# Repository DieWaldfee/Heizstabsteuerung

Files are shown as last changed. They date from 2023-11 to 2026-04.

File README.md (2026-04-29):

# Heizstabsteuerung

Heizstabsteuerung (Platine und Software) zur Ansteuerung eines Heizstabs in einem Pufferspeicher (Heizung)

**zugehörige Repositories**<br>

- PowerGuard (Steuerungsplatine <a href="https://github.com/DieWaldfee/PowerGuard"> Link </a>)
- Heizstabsteuerung (dieses Repository)
- Heizstab_ioBroker (Ansteuerungs-Blockly - ein MQTT-Broker wird benötigt - Link)

**Funktion:** <br>
Der ESP32 steuert 3 Temperatursensoren (DS18B20) an und liest diese aus. Zwei der Sensoren sollen am Referenzpunkt der Heizungsanlage (an Pufferspeichers der Heizung) angebracht werden, in dem auch der elektrische Heizstab eingeschraubt ist.
Die beiden Werte werden einerseits verglichen und andererseits benutzt, um die Pufferspeichertemperatur zu überwachen. Liegt die Temperatur zu hoch, dann ist zu viel Energie im Pufferspeicher und vermutlich ist der Heizstab dafür ursächlich -> der Heizstabsteuerung abgeschaltet (L1, L2, L3)und damit in den sicheren Zustand überführt.<p>
Liegt die Temperatur der beiden Sensoren über der eingestellten, kritischen Temperatur, so schaltet sich der ESP32 ganz ab und meldet dies optisch über die rote LED. Die Standardschaltung erfolgt über die beiden Sensoren. Eine Fehlerabschaltung erfolgt auch, wenn die Werte der Sensoren zu stark differieren (float deltaT = 2.0;).
Der dritte Sensor wird am höchsten Punkt des Pufferspeichers angebracht und dient der Überwachung der maximal zulässigen Puffertemperatur. Der Sensorwert wird zur Notabschaltung des ESP verwendet, sollte der Puffer signifikat zu heiß werden.
Die Kommunikation mit dem ESP32 wird über WiFi abgewickelt und über das Protokoll MQTT umgesetzt. Es stehen mehrere Befehle zur Verfügung, die ebenfalls via MQTT an den ESP gesendet werden kann. Neben "restart" (führt zu einem Neutstart des ESP32) kann die ganze Konfiguration un der debug-Level angepasst werden. Alle Anpassungen sind nach einem Neustart verlohren, da diese nicht permanet gespeichter werden (aber neue Parameter flashen geht ja fix). Befehle werden unter der MQTT-Hierarchie in folgendem Ort empfangen: "SmartHome/Keller/Heizung/ESP32_Heizstabsteuerung/command" (MQTT_SERIAL_RECEIVER_COMMAND)

**Hardwarevarianten:** <br>
Das Programm unterstützt zwei Hardwarevarianten in einem gemeinsamen Code. Die Auswahl erfolgt über den Parameter `HARDWARE_VERSION` in `src/secrets.h`:

- `HARDWARE_VERSION 1` → V1.0 Lochrasterplatine (OK-LED + ERROR-LED)
- `HARDWARE_VERSION 2` → V2.0 Platinenversion/PCB (OK-LED + MSG-LED + ERROR-LED)

**Entwicklungsumgebungen:** <br>
Die Software für den ESP32 wird mit **PlatformIO** (VSCode-Extension) entwickelt. Compile und Flash sind per Knopfdruck oder über `pio run --target upload` möglich. Die Installation ist sehr einfach und im Netz gut dokumentiert.<br>
Die Platine (PCB) habe ich in Eagle von AutoCAD modelliert. Für Maker gibt es eine kostenfreie Version. Die CAM-Daten (PCB-Produktionsdaten), sowie die BOM (Stückliste) sind ebenfalls aus Eagle ausgegeben.
Eine Übersichtsversion der Platine ist mit Fritzing umgesetzt und enthält auch einige Notizen zur Pinbelegung.<br>

**benötigte Umgebung:** <br>

- ioBroker zur Ansteuerung (geht natürlich auch mit anderen SmartHome-Systemen, solange diese MQTT sprechen können)
- ioBroker MGTT-Adapter
- MQTT-Broker: z.B. mosquitto unter Linux/Debian/Raspian...
- 230V Stromversorgung oder alternativ eine 5V Versorgung über z.B. ein USB-Ladegerät (muss 2 ESP32 sicher versorgen können -> 2A reicht völlig aus) oder über die Schraubklemmen anderweitig versorgt.

### Abhängigkeiten (PlatformIO – platformio.ini):

| Header | Bibliothek |
| --- | --- |
| `OneWire.h` | OneWire git-master (v2.3.7 inkompatibel mit ESP-IDF 5.x; v2.3.8 hat einen Bug – git-master enthält den Fix) |
| `DallasTemperature.h` | DallasTemperature by Miles Burton v4.0.4 |
| `WiFi.h` | Arduino / ESP32-Framework |
| `WiFiClient.h` | Arduino / ESP32-Framework |
| `PubSubClient.h` | PubSubClient by Nick O'Leary v2.8 |
| `Wire.h` | Arduino / ESP32-Framework |
| `LiquidCrystal_I2C.h` | LiquidCrystal_I2C by Frank de Brabander ^1.1.0 |
| `EmonLib.h` | EmonLib-esp32 – ESP32-optimierter Fork |
| `esp_task_wdt.h` | Espressif Framework |

### Board ESP32

Platform: `https://github.com/pioarduino/platform-espressif32` (Release 55.03.38-1)<br>
Board: `esp32dev`, Framework: `arduino`<br>

**aktuelle Versionen:** <br>

- ESP-Software V2.0.2
- PCB (Eagle) V2.0.1
- CAM V1.0
- BOM V2.0
- Fritzing V2.0

Die PCB V2.x ist für einen Platinenhersteller konstruiert => CAM-files können einfach der Bestellung beigefügt werden (z.B. bei https://jlcpcb.com für 2$ 5St Stand 11.11.2023) und ein paar Tage später ist die Platine fertig..
In der BOM findet sich die Stückliste für die Bestückung wieder.



Zugehöriges Projekt: https://github.com/users/DieWaldfee/projects/1

**Installation:**

- `src/secrets.h.example` nach `src/secrets.h` kopieren und eigene Zugangsdaten eintragen:<br>
  &nbsp;&nbsp;&nbsp;– WLAN-SSID, WLAN-Passwort, Hostname<br>
  &nbsp;&nbsp;&nbsp;– MQTT-Broker (IP, Port, User, Passwort)<br>
  &nbsp;&nbsp;&nbsp;– Hardwarevariante: `HARDWARE_VERSION 1` (Lochraster) oder `HARDWARE_VERSION 2` (Platine)<br>
  &nbsp;&nbsp;&nbsp;
- MQTT-Pfade sind in `src/Heizstabsteuerung.cpp` als `#define` hinterlegt und müssen in der Regel nicht geändert werden. <br>
  &nbsp;&nbsp;&nbsp;
- Adressen der DS18B20-Sensoren ermitteln und in `src/Heizstabsteuerung.cpp` eintragen. Hierzu muss der Debuglevel auf 1 gestellt werden (MQTT-Befehl `debug=1`) und die Ausgabe im Serial Monitor beobachtet werden. OnStart gibt der ESP32 die Sensoradressen aus.<br>
  &nbsp;&nbsp;&nbsp;
- Kalibrierung der Stromsensoren: Hierzu das separate Projekt **STC013_cal** (Sternverschaltung) bzw. **STC013_Dreieck_cal** (Dreiecksverschaltung) verwenden (siehe Abschnitt _Nachträgliche Kalibrierung_). <br>
  &nbsp;&nbsp;&nbsp;
- Bei Fehlern kann per MQTT-Befehl `debug=<0-3>` der Debug-Level für die Ausgaben auf den Serial Monitor eingestellt werden: 0 = BootUp only; 1 = Basic; 2 = Advanced; 3 = Absolut
- ESP-Software wird über PlatformIO auf das "ESP32 Dev Kit" compiliert und übertragen.
- Platine entweder via Eagle an PCB-Hersteller übermitteln oder mit einer Lochrasterplatine per Hand aufbauen.
- Platine bestücken + ESP und Level-Shifter (3.3V <-> 5V) aufsetzen.
- Relais anschließen.
- 12V Versorgung der Heizstabsteuerung wird über LED-Treiber realisiert.

**Displayinhalte:**

- Zeile 1;
  - L1 => Leiter 1 / Phase 1
  - L2 => Leiter 2 / Phase 2
  - L3 => Leiter 3 / Phase 3
  - hinter Lx: "-" => nicht geschaltet; "\*" => geschaltet
  - hinter Schaltzustand: "-" => ungeprüft; "x" => Fehler zwischen Strommessung und Soll-Schaltzustand; ":heavy_check_mark:" => Strommessung korrekt vs. Sollschaltzustand geprüft
  - hinter dem Block L3 folgt das Symbol für den Lüfterzustand: " " => Lüfter nicht geschaltet; ">>Lüftersymbol<<" => Lüfter geschaltet
  - hinter dem Lüftersymbol folgt MQTT-Symbol: " " => kein MQTT-Verbindung gegeben; "<<Wifi-Symbol>>" => MQTT-Verbingung aktiv
    Zeile 2:
  - T_Top: Temperatursensor am obersten Messpunkt - dient der Safety, um nicht zu überhitzen [°C]
  - T_Messpunkt_1: erste Messung auf der Entschiedungsebene (in der Regel parallel zum Sensor der Heizung) [°C]
  - T_Messpunkt_2: zweite Messung auf der Entschiedungsebene [°C]

**Steuerung:**

- Befehle werden über MQTT auf `/command` gesendet (Topic: `SmartHome/Keller/Heizung/ESP32_Heizstabsteuerung/command`).
- Befehlsliste (alle Befehle liegen in der MQTT-Callback-Funktion `void mqttCallback(...)`):
  - "L1 ein": schaltet L1 ein
  - "L1 aus": schaltet L1 aus
  - "L2 ein": schaltet L2 ein
  - "L2 aus": schaltet L2 aus
  - "L3 ein": schaltet L3 ein
  - "L3 aus": schaltet L3 aus
  - "L12 ein": schaltet L1 und L2 ein
  - "L12 aus": schaltet L1 und L2 aus
  - "L13 ein": schaltet L1 und L3 ein
  - "L13 aus": schaltet L1 und L3 aus
  - "L23 ein": schaltet L2 und L3 ein
  - "L23 aus": schaltet L2 und L3 aus
  - "L123 ein": schaltet L1, L2 und L3 ein
  - "L123 aus": schaltet L1, L2 und L3 aus
  - "Fan ein" / "Fan aus": schaltet den Lüfter ein/aus
  - "IrmsOn": startet die Stromsensor-Auswertung (befüllt Irms11/21/31 – Phase ein)
  - "IrmsOff": startet die Stromsensor-Auswertung (befüllt Irms10/20/30 – Phase aus)
  - "debug=\<0-3\>": setzt den Debug-Level (0=BootUp only; 1=Basic; 2=Advanced; 3=Absolut)
  - "panicMode=0": setzt den panicMode zurück
  - "thermalError=0" / "thermalError=1": setzt thermalError
  - "thermalLimit=0" / "thermalLimit=1": setzt thermalLimit
  - "checkError=0" / "checkError=1": setzt checkError
  - "ErrorLED aus": quittiert die Fehler-LED
  - "restart" / "reboot": führt zu einem Neustart des ESP32

**Nachträgliche Kalibrierung der Strommessung:**

Die SCT-013-Stromsensoren müssen für eine genaue Leistungsmessung individuell kalibriert werden, da ADC-Eingangswiderstände und Sensorexemplare streuen. Für die Kalibrierung stehen zwei separate PlatformIO-Projekte bereit — je nach Verschaltung des Heizstabs.

**Voraussetzungen:**

- Zangenampermeter zur Referenzmessung an allen drei Phasen
- Serieller Monitor (115200 Baud)
- Der Heizstab muss während der Lastmessung vollständig betriebsbereit angeschlossen sein

---

**Sternverschaltung — `STC013_cal` / `STC013_cal.cpp`**

Bei einem sternverschalteten Heizstab trägt jede Phase eine unabhängige Wicklung. Die Phasen werden nacheinander einzeln zugeschaltet.

Ablauf:

1. Referenzwerte mit dem Zangenampermeter unter Last an L1, L2 und L3 messen.
2. Die gemessenen Ströme in den Variablen `Irms_L1_xA`, `Irms_L2_xA`, `Irms_L3_xA` eintragen.
3. Sketch flashen und seriellen Monitor öffnen.

Der Sketch führt für jede Phase automatisch zwei Messreihen durch:

- **Nullmessung** (Last aus): 10 Messungen ohne Strom; die ersten 3 werden verworfen. Der Mittelwert der verbleibenden 7 Messungen ergibt den empfohlenen neuen Wert für `ADC_LX_zeroCorr`. Dieser Offset korrigiert den Leckstrom des Sensors im stromlosen Zustand.
- **Lastmessung** (Last ein): Das zugehörige SSR wird zugeschaltet. Aus dem Mittelwert der 7 gültigen Messungen und dem Referenzwert vom Zangenampermeter berechnet der Sketch den neuen `ADC_LX_corr`-Faktor nach der Formel:

```
ADC_LX_corr_neu = (Irms_Referenz / Irms_gemessen) * ADC_LX_corr_alt
```

4\. Die ausgegebenen Korrekturwerte für `ADC_LX_corr` und `ADC_LX_zeroCorr` in `src/Heizstabsteuerung.cpp` übernehmen und neu flashen.

Der `loop()` wiederholt die gesamte Messreihe automatisch, sodass mehrere Durchläufe für eine stabile Mittelung genutzt werden können.

---

**Dreiecksverschaltung — `STC013_Dreieck_cal` / `STC013_Dreieck_cal.cpp`**

Bei einem dreiecksverschalteten Heizstab fließen die Strangströme durch die Wicklungen zwischen den Phasen. Die Kalibrierung erfolgt stufenweise, weil sich der Laststrom in L3 erst bei Stufe 2 (alle drei Phasen aktiv) vollständig ausbildet.

Schaltstufen:

| Stufe | Aktive Phasen | Beschreibung |
| ----- | --- | --- |
| 1 | L1 + L2 | Eine Dreieckwicklung zwischen L1 und L2 |
| 2 | L1 + L2 + L3  | Alle drei Wicklungen aktiv |

Ablauf:

1. Referenzwerte mit dem Zangenampermeter messen:
   - L1 und L2 in **Stufe 1** (nur L1 + L2 eingeschaltet)
   - L3 in **Stufe 2** (alle drei Phasen eingeschaltet)
2. Werte eintragen: `Irms_L1_xA` und `Irms_L2_xA` für Stufe 1, `Irms_L3_xA` für Stufe 2.
3. Sketch flashen und seriellen Monitor öffnen.

Der Sketch führt zunächst Nullmessungen für alle drei Sensoren durch (alle Phasen aus), dann:

- **Stufe 1**: L1 und L2 werden zugeschaltet — Kalibrierung von `ADC_L1_corr` und `ADC_L2_corr`
- **Stufe 2**: L3 wird zusätzlich zugeschaltet — Kalibrierung von `ADC_L3_corr`

Auch hier werden je 10 Messungen durchgeführt, die ersten 3 verworfen und aus den verbleibenden 7 der Mittelwert gebildet. Die Korrekturformel ist identisch zur Sternverschaltung.

4\. Die ausgegebenen Korrekturwerte für `ADC_LX_corr` und `ADC_LX_zeroCorr` in `src/Heizstabsteuerung.cpp` übernehmen und neu flashen.

---

**Kalibrierparameter in `src/Heizstabsteuerung.cpp`:**

| Parameter | Bedeutung |
| --- | --- |
| `ADC_L1_corr` / `ADC_L2_corr` / `ADC_L3_corr` | Skalierungsfaktor für EmonLib (Rohwert → Ampere) |
| `ADC_L1_zeroCorr` / `ADC_L2_zeroCorr` / `ADC_L3_zeroCorr` | Offset-Korrektur für Leckstrom bei stromlosem Sensor |

---

Alternativ kann die manuelle Methode über MQTT verwendet werden:

- Phasenlimits temporär erhöhen: `phasen1Limit=100`
- Phasen ausschalten: `L123 aus`, dann `IrmsOff` → Irms10/20/30 werden befüllt
- Phasen einschalten: `L123 ein`, dann `IrmsOn` → Irms11/21/31 werden befüllt
- Tatsächlichen Strom parallel mit Zangenampermeter messen
- Korrekturwerte berechnen: ADC_L1_corr = Asoll/Aist × 15A
- Phasen ausschalten: `L123 aus`, dann `reboot`

**Bezugsquellen:**

- Platinennetzteil AC-05-3 <a href="https://www.azdelivery.de/products/copy-of-220v-zu-5v-mini-netzteil"> AZ-Delivery </a>
- Levelshifter (3.3V <-> 5V) <a href="https://www.amazon.de/RUNCCI-YUN-Pegelwandler-Converter-BiDirektional-Mikrocontroller/dp/B082F6BSB5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"> Amazon </a>
- Relais <a href="https://www.amazon.de/gp/product/B0B5816YJ7/ref=ppx_yo_dt_b_search_asin_image?ie=UTF8&th=1"> Amazon </a> oder <a href="https://www.az-delivery.de/products/relais-modul"> AZ Delivery </a>
- SSR-40DA, Eingang 4-32VDC <a href="https://www.amazon.de/gp/product/B071HP9NJD/ref=ppx_yo_dt_b_search_asin_title?ie=UTF8&psc=1"> Amazon </a>
- 12V LED-Treiber als Schaltspannung der SSR-Relais <a href="https://www.amazon.de/gp/product/B082NLNCSB/ref=ppx_yo_dt_b_search_asin_image?ie=UTF8&psc=1"> Amazon </a>
- JST-Buchse <a href="https://www.amazon.de/gp/product/B0B2R99X99/ref=ppx_yo_dt_b_search_asin_title?ie=UTF8&psc=1"> Amazon </a>
- Klemmbuchse <a href="https://www.amazon.de/gp/product/B087RN8FDZ/ref=ppx_yo_dt_b_search_asin_title?ie=UTF8&th=1"> Amazon </a>
- Widerstände 4,7kOhm, 220 Ohm, 330 Ohm, Led grün und rot Amazon / eBay / Conrad...
- Temperatursensoren DS18B20 <a href="https://www.az-delivery.de/products/2er-set-ds18b20-mit-3m-kabel"> AZ Delivery </a>
- Display 16x2 (I2C) <a href="https://www.az-delivery.de/products/bundlelcd-schnittstelle"> AZ Delivery </a>
- Sensor SCT013 (15A-Version) <a href="https://www.ebay.de/itm/401649505325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"> eBay </a>

**fertige Steuerung:**

(Displayanzeige mit Schaltzustand der Phasen L1-L3, Lüfter, MQTT-Connect in der ersten Zeile. DIe zweite Zeile zeigt die Temperaturen Max am höchsten Punkt und den Sensor 1 und 2 am Relegungspunkt)

(bestückte Heizstabsteuerung mit angeschlossenen Strom-Sensoren und Display - ohne Temperatursensoren)

(bestückte Heizstabsteuerung mit angeschlossenen Strom-Sensoren und Display - ohne Temperatursensoren)

(Gesamtschaltung am Pufferspeicher - links die Steuerung und rechts die SSR-Relais und deren Kühlkörper)

**Haftungsausschluss**<br>
Deutsch: Dieses Projekt arbeitet mit Netzspannung (220 V) und darf ausschließlich von qualifiziertem Fachpersonal aufgebaut, installiert und betrieben werden. Durch die anliegende Spannung besteht Lebensgefahr! Fehler in Schaltung oder Software können zu Sachschäden (z. B. an Gebäude oder Heizung) oder zu gefährlichen Situationen für Leib und Leben führen. Nutzung auf eigene Gefahr – jegliche Haftung wird ausgeschlossen.
<br>
English: This project operates with mains voltage (220 V) and must only be assembled, installed, and operated by qualified professionals. The present voltage poses a risk of fatal electric shock! Errors in circuitry or software may cause property damage (e.g., to buildings or heating systems) or create life-threatening situations. Use at your own risk – any liability is disclaimed.

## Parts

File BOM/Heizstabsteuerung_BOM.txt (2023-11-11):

Stückliste exportiert aus C:/ESP32_Projekte/Heizstabsteuerung/Eagle/Heizstabsteuerung_V2.02.sch am 11.11.2023 21:42

Part    Value              Device             Package            Description                                         AVAILABILITY CHECK_PRICES                                                                     DESCRIPTION                                                MF                                                                                         MP                MPN           OC_FARNELL OC_NEWARK PACKAGE POPULARITY PRICE PURCHASE-URL                                           SNAPEDA_LINK SPICEPREFIX                                                                      
C1      10µF               CPOL-EUE2.5-5      E2,5-5             POLARIZED CAPACITOR, European symbol                                                                                                                                                                                                                                                                                                                                 16                                                                                   C                                                                                
C2      10µF               CPOL-EUE2.5-5      E2,5-5             POLARIZED CAPACITOR, European symbol                                                                                                                                                                                                                                                                                                                                 16                                                                                   C                                                                                
C3      10µF               CPOL-EUE2.5-5      E2,5-5             POLARIZED CAPACITOR, European symbol                                                                                                                                                                                                                                                                                                                                 16                                                                                   C                                                                                
CON1                       WAGO-500-2         WAGO-500-2         WAGO SCREW CLAMP                                                                                                                                                                                                                                                                                                          237-102       unknown    70K9898           32                                                                                                                                                                    
CON2    JST-XH-03          JST-XH-03          JST-XH-03                                                                                                                                                                                                                                                                                                                                                                                                                                                                                                                                                     
CON3    JST-XH-03          JST-XH-03          JST-XH-03                                                                                                                                                                                                                                                                                                                                                                                                                                                                                                                                                     
CON4    JST-XH-03          JST-XH-03          JST-XH-03                                                                                                                                                                                                                                                                                                                                                                                                                                                                                                                                                     
JP1     Display 16x2       JP4E               JP4                JUMPER                                                                                                                                                                                                                                                                                                                                                               15                                                                                                                                                                    
JP3     L1                 JP1E               JP1                JUMPER                                                                                                                                                                                                                                                                                                                                                               61                                                                                                                                                                    
JP4     L2                 JP1E               JP1                JUMPER                                                                                                                                                                                                                                                                                                                                                               61                                                                                                                                                                    
JP5     L3                 JP1E               JP1                JUMPER                                                                                                                                                                                                                                                                                                                                                               61                                                                                                                                                                    
LED1    rot                LED3MM             LED3MM             LED                                                                                                                                                                                                                                                                                                                                                                  97                                                                                                                                                                    
LED2    grün               LED3MM             LED3MM             LED                                                                                                                                                                                                                                                                                                                                                                  97                                                                                                                                                                    
LED3    gelb               LED3MM             LED3MM             LED                                                                                                                                                                                                                                                                                                                                                                  97                                                                                                                                                                    
LS_SSR1 LEVELSHIFTER       LEVELSHIFTER       LEVELSHIFTER       Logic Level Converter - Bi-Direc Check availability In Stock                                                                                       BSS138 Logic-Level Translator Interface Evaluation Board  SparkFun                                                                                   BOB-12009                                            None               None  https://pricing.snapeda.com/search?q=BOB-12009&ref=eda                                                                                               
R1      220                R_10MM0207/10      0207/10            RESISTOR, European symbol                                                                                                                                                                                                                                                                                                                                            81                                                                                   R                                                                                
R2      330                R_10MM0207/10      0207/10            RESISTOR, European symbol                                                                                                                                                                                                                                                                                                                                            81                                                                                   R                                                                                
R3      10k                R_10MM0207/10      0207/10            RESISTOR, European symbol                                                                                                                                                                                                                                                                                                                                            81                                                                                   R                                                                                
R4      4.7 k              R_10MM0207/10      0207/10            RESISTOR, European symbol                                                                                                                                                                                                                                                                                                                                            81                                                                                   R                                                                                
R5      10k                R_10MM0207/10      0207/10            RESISTOR, European symbol                                                                                                                                                                                                                                                                                                                                            81                                                                                   R                                                                                
R6      10k                R_10MM0207/10      0207/10            RESISTOR, European symbol                                                                                                                                                                                                                                                                                                                                            81                                                                                   R                                                                                
R7      10k                R_10MM0207/10      0207/10            RESISTOR, European symbol                                                                                                                                                                                                                                                                                                                                            81                                                                                   R                                                                                
R8      10k                R_10MM0207/10      0207/10            RESISTOR, European symbol                                                                                                                                                                                                                                                                                                                                            81                                                                                   R                                                                                
R9      10k                R_10MM0207/10      0207/10            RESISTOR, European symbol                                                                                                                                                                                                                                                                                                                                            81                                                                                   R                                                                                
R10     220                R_10MM0207/10      0207/10            RESISTOR, European symbol                                                                                                                                                                                                                                                                                                                                            81                                                                                   R                                                                                
SV1                        FE06-1             FE06               FEMALE HEADER                                                                                                                                                                                                                                                                                                                           unknown    unknown           11                                                                                                                                                                    
SV2                        FE06-1             FE06               FEMALE HEADER                                                                                                                                                                                                                                                                                                                           unknown    unknown           11                                                                                                                                                                    
U$1     LOGO_RAUCHSCHWALBE LOGO_RAUCHSCHWALBE LOGO_RAUCHSCHWALBE                                                                                                                                                                                                                                                                                                                                                                                                                                                                                                                                            
U1      ESP32-DEV-KIT-V4   ESP32-DEV-KIT-V4   ESP32-DEV-KIT-V4   ESP32-DEVKITC Check availability                    In Stock     https://www.snapeda.com/parts/ESP32-DEVKITC/Espressif+Systems/view-part/?ref=eda  ESP32-WROOM-32UE series Transceiver                        802.11 b/g/n (Wi-Fi, WiFi, WLAN), Bluetooth ® Smart Ready 4.x Dual Mode Evaluation Board  Espressif Systems ESP32-DEVKITC                              None             None                                                                https://www.snapeda.com/parts/ESP32-DEVKITC/Espressif+Systems/view-part/?ref=snap

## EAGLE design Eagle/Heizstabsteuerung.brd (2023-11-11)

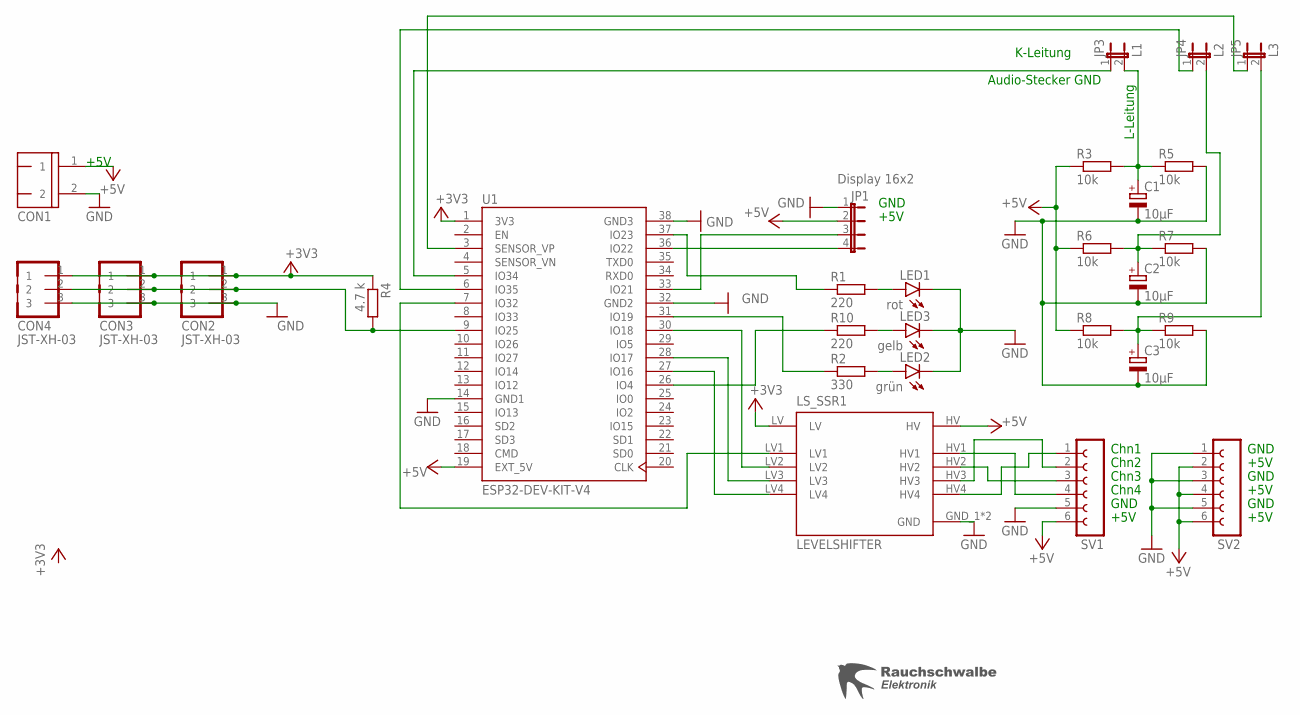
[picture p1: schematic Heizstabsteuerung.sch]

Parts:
C1, C2, C3: 10µF; E2,5-5
CON1: WAGO-500-2
CON2, CON3, CON4: JST-XH-03
JP1: Display 16x2; JP4
JP3: L1; JP1
JP4: L2; JP1
JP5: L3; JP1
LED1: rot; LED3MM
LED2: grün; LED3MM
LED3: gelb; LED3MM
LS_SSR1: LEVELSHIFTER
R1, R10: 220; 0207/10
R2: 330; 0207/10
R3, R5, R6, R7, R8, R9: 10k; 0207/10
R4: 4.7 k; 0207/10
SV1, SV2: FE06-1; FE06
U1: ESP32-DEV-KIT-V4
U$1: LOGO_RAUCHSCHWALBE

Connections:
+3V3: CON2.1, CON3.1, CON4.1, LS_SSR1.LV, R4.1, U1.1 (3V3)
+5V: CON1.1, JP1.2, LS_SSR1.HV, R3.1, R6.1, R8.1, SV1.6, SV2.2, SV2.4, SV2.6, U1.19 (EXT_5V)
GND: C1.-, C2.-, C3.-, CON1.2, CON2.3, CON3.3, CON4.3, JP1.1, LED1.K (C), LED2.K (C), LED3.K (C), LS_SSR1.GND_1 (GND), LS_SSR1.GND_2 (GND), R5.2, R7.2, R9.2, SV1.5, SV2.1, SV2.3, SV2.5, U1.14 (GND1), U1.32 (GND2), U1.38 (GND3)
unnamed: R1.1, U1.37 (IO23)
unnamed: C1.+, JP3.2, R3.2, R5.1
unnamed: LED3.A, R10.2
unnamed: JP1.3, U1.33 (IO21)
unnamed: JP1.4, U1.36 (IO22)
unnamed: R2.1, U1.31 (IO19)
unnamed: LED1.A, R1.2
unnamed: LED2.A, R2.2
unnamed: LS_SSR1.HV4, SV1.1
unnamed: LS_SSR1.LV1, U1.7 (IO32)
unnamed: CON2.2, CON3.2, CON4.2, R4.2, U1.9 (IO25)
unnamed: JP3.1, U1.5 (IO34)
unnamed: LS_SSR1.LV4, U1.27 (IO16)
unnamed: LS_SSR1.LV3, U1.28 (IO17)
unnamed: LS_SSR1.LV2, U1.30 (IO18)
unnamed: R10.1, U1.26 (IO4)
unnamed: LS_SSR1.HV1, SV1.4
unnamed: LS_SSR1.HV2, SV1.3
unnamed: LS_SSR1.HV3, SV1.2
unnamed: JP4.1, U1.6 (IO35)
unnamed: JP5.1, U1.3 (SENSOR_VP)
unnamed: C2.+, JP4.2, R6.2, R7.1
unnamed: C3.+, JP5.2, R8.2, R9.1

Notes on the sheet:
GND
+5V
Chn1
Chn2
Chn3
Chn4
K-Leitung
L-Leitung
Audio-Stecker GND

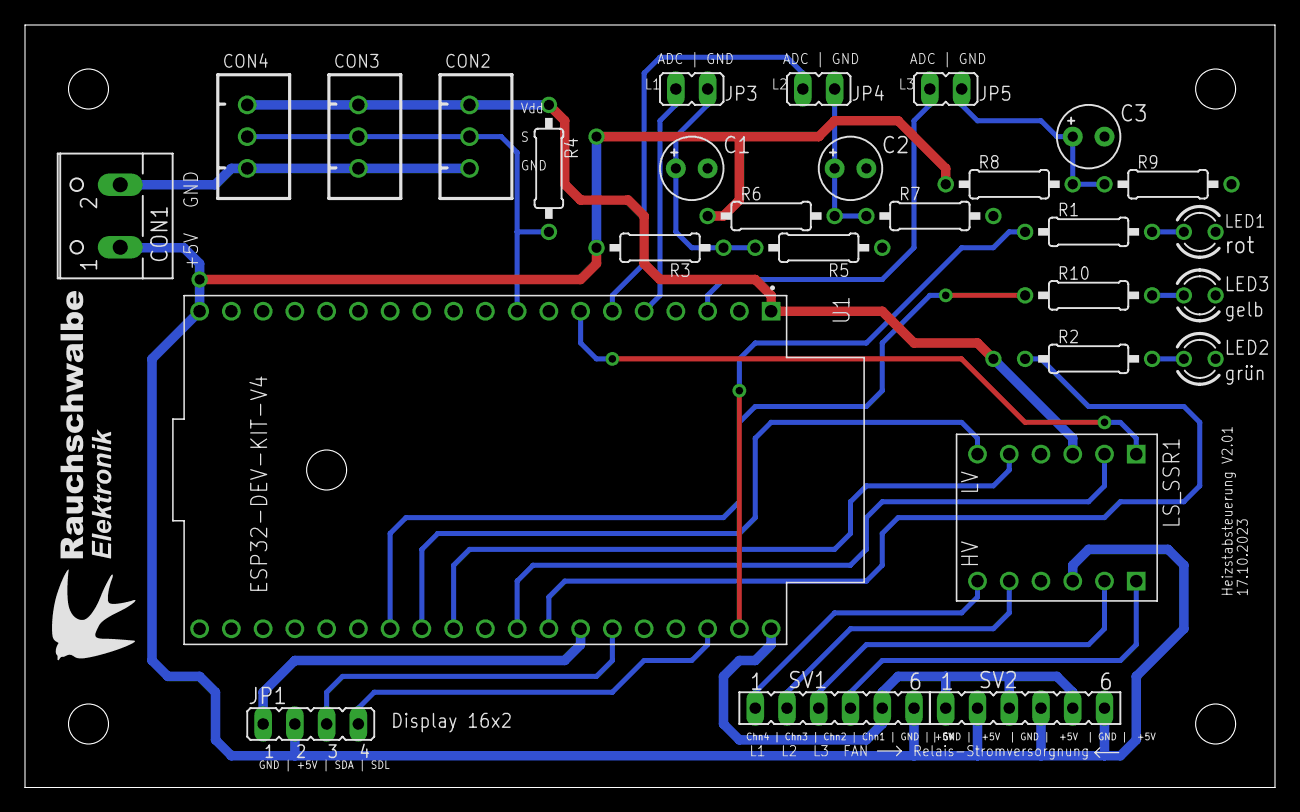
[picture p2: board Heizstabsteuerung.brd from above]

Board: 2 copper layers, 100.0 x 61.0 mm, 29 parts (0 on the bottom side), 26 nets.

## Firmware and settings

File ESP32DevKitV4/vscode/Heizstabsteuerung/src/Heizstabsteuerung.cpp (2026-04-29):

// https://beelogger.de/sensoren/temperatursensor-ds18b20/ für Pinning und
// Anregung
#include <DallasTemperature.h>
#include <EmonLib.h>  // Auswertung der SCT013-Sensoren
#include <LiquidCrystal_I2C.h>
#include <OneWire.h>
#include <PubSubClient.h>
#include <WiFi.h>
#include <WiFiClient.h>
#include <Wire.h>
#include <esp_task_wdt.h>

#include "hardware.h"
#include "secrets.h"

static byte debug = 0;
static String lastError = "";

// Sicherheitsfunktionen
int volatile thermalError = 0;        // Indikator für die thermische Zwangsabschaltung - die Obergrenze die
                                      // Max-Sensors ist überschritten -> PanicMode = 1
int volatile thermalLimit = 0;        // Indikator, das die maximale Temperatur am Top-Sensor überschritten
                                      // wurde. Phasen werden abgeschalten.
int volatile thermalMaxOverheat = 0;  // Indikator, das die maximale Temperatur am Max-Sensor überschritten
                                      // wurde. Phasen werden abgeschalten.
int volatile panicMode = 0;           // Indikator für die Zwangsabschaltung - ab jetzt
                                      // wird nichts mehr zugeschaltet

// Analogeingaenge zur Stromueberwachung
// https://randomnerdtutorials.com/esp32-adc-analog-read-arduino-ide/
float volatile amp1 = 0.0;     // Phasenstrom Phase 1
float volatile amp2 = 0.0;     // Phasenstrom Phase 2
float volatile amp3 = 0.0;     // Phasenstrom Phase 3
float volatile Irms10 = 0.0;   // Stromwert L1 aus. Irms-Rohdaten werden durch getAmpCore() gefüllt.
                               // Dient der späteren Kalibrierung von ADC_L1_corr
float volatile Irms11 = 15.0;  // Stromwert L1 ein. Irms-Rohdaten werden durch getAmpCore() gefüllt.
                               // Dient der späteren Kalibrierung von ADC_L1_corr
float volatile Irms20 = 0.0;   // Stromwert L2 aus. Irms-Rohdaten werden durch getAmpCore() gefüllt.
                               // Dient der späteren Kalibrierung von ADC_L2_corr
float volatile Irms21 = 15.0;  // Stromwert L2 ein. Irms-Rohdaten werden durch getAmpCore() gefüllt.
                               // Dient der späteren Kalibrierung von ADC_L2_corr
float volatile Irms30 = 0.0;   // Stromwert L3 aus. Irms-Rohdaten werden durch getAmpCore() gefüllt.
                               // Dient der späteren Kalibrierung von ADC_L3_corr
float volatile Irms31 = 15.0;  // Stromwert L3 ein. Irms-Rohdaten werden durch getAmpCore() gefüllt.
                               // Dient der späteren Kalibrierung von ADC_L3_corr
#define ZEROHYST 0.8           // +- xA ZeroHyst um 0A = aus - sonst an
EnergyMonitor emon1;
EnergyMonitor emon2;
EnergyMonitor emon3;
// Kalibrierung auf den verwendeten Sensor erforderlich - Ausgleich von
// Toleranzen! Initialwerte aus hardware.h – via MQTT zur Laufzeit änderbar.
float ADC_Sensor[3] = {15.0, 15.0, 15.0};       // Sensorwert pro Volt Ausgabe je Phase (15.0 bei 15A/V)
float ADC_L1_corr = ADC_L1_CORR_INIT;           // Korrektur L1-Sensor (Peaklast)
float ADC_L2_corr = ADC_L2_CORR_INIT;           // Korrektur L2-Sensor (Peaklast)
float ADC_L3_corr = ADC_L3_CORR_INIT;           // Korrektur L3-Sensor (Peaklast)
float ADC_L1_zeroCorr = ADC_L1_ZERO_CORR_INIT;  // Nullpunktkorrektur L1 @0A
float ADC_L2_zeroCorr = ADC_L2_ZERO_CORR_INIT;  // Nullpunktkorrektur L2 @0A
float ADC_L3_zeroCorr = ADC_L3_ZERO_CORR_INIT;  // Nullpunktkorrektur L3 @0A

// Schaltausgaenge für Phase 1-3 und Luefter
const int PHASE_PIN[3] = {PHASE1, PHASE2, PHASE3};  // Array für switchPhase() / queuePhaseCheck()
volatile int phaseOn[3] = {0, 0, 0};                // Schaltzustände L1/L2/L3: on(<>0) / off(=0)
int volatile fanOn = 0;                             // Indikator, ob der Lüfter on (<>1) / off (=0) geschaltet ist
int phaseError[3] = {0, 0, 0};                      // Fehlerflag L1/L2/L3 (Strom/Schaltinkonsistenz)
int volatile checkError = 0;                        // Indikator, ob ein Statuscheck der Ströme &
                                                    // Schaltzustände inkonsistent ist
int phasenLimit[3] = {15, 15, 15};                  // Stromlimits L1/L2/L3 [A]
int phaseTimeCheck = 2000;                          // prüfe nach 2000 Ticks = 2sec, ob der
                                                    // Schaltzustand der Phase eingestellt wurde
#define INTEGRETY_INTERVAL 5000                     // Interval, in dem die Integrität geprüft wird. 5.000 Ticks = 5s
TickType_t lastSwitch = 0;                          // Zeitpunkt des letzten Schaltvorgangs - bei Überlauf der TickTime
                                                    // besteht akzeptierte potentielle Pause der Integritätsprüfung
#define INTEGRETY_DELAY \
  2000  // frühester Zeitpunkt für eine Integritätsprüfung nach einem
        // Schaltvorgang: 2000 Ticks = 2s

// Konfigurationsstruktur für den generischen Phasencheck-Task
typedef struct {
  QueueHandle_t ampQueue;     // Queue mit Schaltvorgängen dieser Phase (amp1Queue etc.)
  QueueHandle_t freeQueue;    // Freigabe-Queue für Integritätscheck (free1Queue etc.)
  volatile float* ampGlobal;  // Zeiger auf globale Stromvariable (amp1 / amp2 / amp3)
  volatile int* phaseOn;      // Zeiger auf Schaltzustand (phase1on / phase2on / phase3on)
  int* phaseError;            // Zeiger auf Fehlerflag (phase1error / phase2error / phase3error)
  int* phaseLimit;            // Zeiger auf Stromlimit (phasen1limit / phasen2limit / phasen3limit)
  int phaseNum;               // Phasennummer (1 / 2 / 3) – nur für Fehlermeldungen / Debug
} PhaseCheckConfig;

// Die drei Konfigurationsinstanzen werden in setup() befüllt
static PhaseCheckConfig phaseCfg1;
static PhaseCheckConfig phaseCfg2;
static PhaseCheckConfig phaseCfg3;

int volatile displayCounter = 0;  // Zähler für die Anzahl der Displayrefreshs. Dient zum zyklischen
                                  // Reinitialisieren des LCD-Treibers
#define MAX_REFRESH_LCD 100       // Anzahl der Displayrefreshs bis das Display reinitialisiert wird.
#define REFRESH_LCD 2000          // Interval für das DisplayUpdate-Task: 2000 Ticks = 2s

// LCD Initialisieren
LiquidCrystal_I2C lcd(LCDADRESS, LCDCOLUMNS, LCDROWS);
// Definition Sonderzeichen für Display
byte okCheck[8] = {0b00000, 0b00011, 0b00010, 0b00010, 0b00010, 0b11010, 0b01010, 0b00100};
byte grad[8] = {0b00100, 0b01010, 0b00100, 0b00000, 0b00000, 0b00000, 0b00000, 0b00000};
byte connIcon[8] = {0b01110, 0b10001, 0b01110, 0b10001, 0b00100, 0b01010, 0b00000, 0b00100};
byte fanIcon[8] = {0b00000, 0b10001, 0b01010, 0b00100, 0b01010, 0b10101, 0b00100, 0b00100};

// Definition der Zugangsdaten WiFi
WiFiClient myWiFiClient;

// Definition der Zugangsdaten MQTT
#define MQTT_CLIENTID "ESP32_Heizstabsteuerung"  // Name muss eineindeutig auf dem MQTT-Broker sein!
#define HST_MQTT_KEEPALIVE 90
#define HST_MQTT_SOCKETTIMEOUT 30
#define MQTT_SERIAL_PUBLISH_STATUS "SmartHome/Keller/Heizung/ESP32_Heizstabsteuerung/status"
#define MQTT_SERIAL_RECEIVER_COMMAND "SmartHome/Keller/Heizung/ESP32_Heizstabsteuerung/command"
#define MQTT_SERIAL_PUBLISH_DS18B20 "SmartHome/Keller/Heizung/ESP32_Heizstabsteuerung/Temperatur/"
#define MQTT_SERIAL_PUBLISH_SCT013 "SmartHome/Keller/Heizung/ESP32_Heizstabsteuerung/Strom/"
#define MQTT_SERIAL_PUBLISH_STATE "SmartHome/Keller/Heizung/ESP32_Heizstabsteuerung/state/"
#define MQTT_SERIAL_PUBLISH_CONFIG "SmartHome/Keller/Heizung/ESP32_Heizstabsteuerung/config/"
#define MQTT_SERIAL_PUBLISH_BASIS "SmartHome/Keller/Heizung/ESP32_Heizstabsteuerung/"
DeviceAddress myDS18B20Address;
unsigned long MQTTReconnect = 0;
#define MQTT_QUEUEDEPTH 50       // Tiefe der MQTT-Queue - 50 Botschaften
#define MQTT_QUEUEMAXWAITTIME 3  // Wartezeit für das Senden in eine Queue - danach Error!
struct MqttJob {                 // Struktur der MQTT-Queue
  char topic[128];               // topic:   Topic auf den die Botschaft gesendet werden soll
                                 // -> 180 Zeichen lang
  char payload[256];             // payload: Botschaft, die an das Topic gesendet werden
                                 // soll. -> 256 Zeichen max.
  bool retain;                   // retain:  true, wenn die Botschaft im Broker gespeichert
                                 // bleibt und false, wenn
};  // nur die angemeldeten User die Botschaft erhalten - diese dann vergessen
    // wird.
PubSubClient mqttClient(myWiFiClient);
static QueueHandle_t mqttQueue;  // Queuedefinition für die MQTT-Queue
static TaskHandle_t hmqtt;       // handler für den MQTT-Sender-Task

// Anzahl der angeschlossenen DS18B20 - Sensoren
int DS18B20_Count = 0;  // Anzahl der erkannten DS18B20-Sensoren
// Beispiel Sensorsetting (Ausgabe im Debugmodus (debug = 1) auf dem serial
// Monitor): DS18B20[0]: 23.69 *C (0x28, 0x88, 0x9d, 0x57, 0x04, 0xe1, 0x3c,
// 0x62) => Slot 2 DS18B20[1]: 23.75 *C (0x28, 0xd2, 0x57, 0x57, 0x04, 0xe1,
// 0x3c, 0x1c) => Slot 1 DS18B20[2]: 23.19 *C (0x28, 0xba, 0x9b, 0x57, 0x04,
// 0xe1, 0x3c, 0x7d) => Slot 3
float volatile tempMax = 0.0;              // Sensor in Slot 1
float volatile tempTop1 = 0.0;             // Sensor in Slot 2
float volatile tempTop2 = 0.0;             // Sensor in Slot 3
const char* Adresse1 = DS18B20_ADDR_MAX;   // tempMax  – Adresse aus hardware.h
const char* Adresse2 = DS18B20_ADDR_TOP1;  // tempTop1 – Adresse aus hardware.h
const char* Adresse3 = DS18B20_ADDR_TOP2;  // tempTop2 – Adresse aus hardware.h
float tempTopLimit = 85.0;                 // Ab dieser Temperatur werden die Phasen 1, 2 und 3
                                           // abgeschalten und der Indikator thermalLimit = 1
float tempMaxLimit = 90.0;                 // Ab dieser Temperatur werden die Phasen 1, 2 und 3 abgeschalten und
                                           // der Indikator thermalLimit = 1 thermalError = 1 & panicMode = 1 ->
                                           // Zwangsabschaltung!
float tempHysterese = 1.0;                 // Phasenzuschaltung erst bei temp < tempTopLimit - tempHysterese -
                                           // verhindert schnelles Schalten um das Limit
float deltaT = 2.0;                        // Limit des Betrags von Differenz zwischen tempTop1
                                           // tempTop2 (|tempTop1-tempTop2|)
float minTemp = 10.0;                      // untere Plausibilitätsgrenze für Temperatursignale. Bei
                                           // Unterschreitung => Notabschaltung, da ggf. Sensor defekt
float maxTemp = 95.0;                      // obere Plausibilitätsgrenze für Temperatursignale. Bei
                                           // Überschreitung => Notabschaltung, da ggf. Sensor defekt
int volatile tempTSensorFail = 0;          // Fehlercounter zur Temperaturmessung - Resilienz gegen gelegentliche
                                           // Fehlauswertungen der Temperatursensoren
int maxTSensorFail = 6;                    // maximal zulässige, hintereinander folgende
                                           // Sensorfehler - danach panicStop
float DS18B20_minValue = -55.0;            // unterster Messwert im Messbereich [°C]
float DS18B20_maxValue = 125.0;            // unterster Messwert im Messbereich [°C]
// Initialisiere OneWire und Thermosensor(en)
OneWire oneWire(ONE_WIRE_BUS);
DallasTemperature myDS18B20(&oneWire);

// Mutexdefinitionen
static SemaphoreHandle_t mutexTemp;
static SemaphoreHandle_t mutexAmp;
static SemaphoreHandle_t mutexI2C;
static SemaphoreHandle_t mutexTempSensor;
static SemaphoreHandle_t mutexAmpSensor;
static SemaphoreHandle_t mutexStatus;
static SemaphoreHandle_t mutexFan;
static SemaphoreHandle_t mutexMQTT;

// TaskRefrechTime
#define MQTTStateRefresh 20000  // Alle 20.000 Ticks = 20sec

// TaskHandler zur Verwendung mit ESP watchdog
static TaskHandle_t htempSensor;
static TaskHandle_t hampSensor;
static TaskHandle_t hintegrity;
static TaskHandle_t hMQTTwatchdog;

// Queue-Definition für Stromüberwachung
#define QUEUEDEPTH 30       // Tiefe der Queue - 30 Schaltvorgänge einer Phase für 5s
#define QUEUEMAXWAITTIME 3  // Wartezeit für das Senden in eine Queue - danach Error!
typedef struct {            // Struktur der Queue-Daten
  TickType_t ticktime;      // gewünchte TickTime der Phasenprüfung
  byte mode;                // geschalteter Zustand ein/aus
} s_queueData;
static QueueHandle_t amp1Queue;   // Queue-Handler für Statuschecks der Phase 1
static QueueHandle_t amp2Queue;   // Queue-Handler für Statuschecks der Phase 2
static QueueHandle_t amp3Queue;   // Queue-Handler für Statuschecks der Phase 3
static bool DataPack = true;      // Datenpaket für die folgenden freeXQueue
static QueueHandle_t free1Queue;  // Queue-Handler - wenn leer, dann
                                  // Integritätscheck Phase 1 durchführbar
static QueueHandle_t free2Queue;  // Queue-Handler - wenn leer, dann
                                  // Integritätscheck Phase 2 durchführbar
static QueueHandle_t free3Queue;  // Queue-Handler - wenn leer, dann
                                  // Integritätscheck Phase 3 durchführbar

// erforderliche Funtions-Prototypen
void allPhasesOff(void);
void panicStop(void);
float getAmp_SCT013(int);
void getAmpCoreOn(void);
void getAmpCoreOff(void);
void thermalStop(void);
bool mqttPublishQueue(const char*, const char*, bool);
void printAmpMQTT(float amp, int p, int pOn);

//-------------------------------------
// Basisfunktion zum sicheren Reset
void safeReset() {
  Serial.println("ESP32 Reset wird vorbereitet...");
  // Sauberes MQTT-Disconnect nur wenn Mutexe existieren (d.h. nicht während setup()-Phase).
  // Ohne diese Prüfung: xSemaphoreTake(NULL) → Assert-Crash wenn safeReset() aus mqttConnect()
  // heraus aufgerufen wird, bevor die Mutex-Initialisierung in setup() stattgefunden hat.
  if (mutexMQTT != nullptr) {
    Serial.println("MQTT Disconnect...");
    xSemaphoreTake(mutexMQTT, pdMS_TO_TICKS(1000));  // best-effort; kein assert - Reboot folgt
    mqttClient.disconnect();
    // kein xSemaphoreGive - blockiert alle MQTT-Operationen anderer Tasks bis Reboot
    delay(50);
    Serial.println("Flush TCP-Buffer...");
    myWiFiClient.clear();
    delay(50);
  }
  Serial.println("ESP32 Reset!");
  ESP.restart();
}

//-------------------------------------
// Wirft den gewünschten Phasencheck in die passende Queue
// mode = 1 -> ein ; mode = 0 -> aus
void queuePhaseCheck(int phase, byte mode) {
  s_queueData dataQueue;

  dataQueue.ticktime = xTaskGetTickCount();
  dataQueue.mode = mode;

  if (debug > 2) Serial.print("Tick ");
  if (debug > 2) Serial.print(dataQueue.ticktime);
  if (debug > 2) Serial.print(" max Tick ");
  if (debug > 2) Serial.print(~TickType_t(0));
  if (debug > 2) Serial.print(" :: Queue aufgerufen: Phase ");
  if (debug > 2) Serial.print(phase);
  if (debug > 2) Serial.print(", Mode ");
  if (debug > 2) Serial.println(mode);

  if (phase < 1 || phase > 3) return;  // Ungültige Phase abfangen
  const int idx = phase - 1;

  // Lokale Lookup-Arrays – kopiert nur Handle-Werte (FreeRTOS-Pointer), kein Overhead
  const QueueHandle_t aq[3] = {amp1Queue, amp2Queue, amp3Queue};
  const QueueHandle_t fq[3] = {free1Queue, free2Queue, free3Queue};

  if (xQueueSendToBack(aq[idx], &dataQueue, QUEUEMAXWAITTIME) == pdPASS) {
    if (xQueueSendToBack(fq[idx], &DataPack, QUEUEMAXWAITTIME) != pdPASS) {
      // Queue voll - Signal bereits gesetzt, kein Fehler
      if (debug) Serial.println("freeQueue voll - Signal bereits gesetzt. (Phase " + String(phase) + ")");
    }
    if (debug > 1) Serial.println("Queue Phase " + String(phase) + " done");
  } else {
    if (debug) Serial.println("Queue Phase " + String(phase) + " ERROR!");
    lastError = "Queue Phase " + String(phase) + " ERROR!";
    panicStop();
  }
}
// Schalte den Lüfter ein oder aus
void switchFan(int mode = 1) {
  BaseType_t rc;
  // mode = 1 -> einschalten
  // mode <> 1 -> ausschalten
  if (panicMode == 0) {
    rc = xSemaphoreTake(mutexFan, portMAX_DELAY);
    assert(rc == pdPASS);
    if (mode == 1) {
      digitalWrite(FAN0, LOW);
      fanOn = 1;
      if (debug) Serial.println("Schaltzustand des Lüfters: eingeschaltet.");
    } else {
      digitalWrite(FAN0, HIGH);
      fanOn = 0;
      if (debug) Serial.println("Schaltzustand des Lüfters: ausgeschaltet.");
    }
    rc = xSemaphoreGive(mutexFan);
    assert(rc == pdPASS);
  } else {
    if (debug) Serial.println("Notaus aktiv -> aktuell keine Lüfterschaltung möglich!");
  }
}
// Schalte eine Phase ein/aus
void switchPhase(int phase, int mode = 0) {
  BaseType_t rc;
  int idx = phase - 1;  // 0-basierter Index: Phase 1→0, Phase 2→1, Phase 3→2
  // mode = 1 -> einschalten; mode <> 1 -> ausschalten
  if ((panicMode + thermalLimit + thermalError + thermalMaxOverheat) == 0) {
    rc = xSemaphoreTake(mutexAmp, portMAX_DELAY);
    assert(rc == pdPASS);
    if (idx >= 0 && idx <= 2) {
      if ((mode == 1) && (phaseError[idx] == 0)) {
        digitalWrite(PHASE_PIN[idx], LOW);
        phaseOn[idx] = 1;
        checkError = 0;  // mögliche Integritätsfehler werden durch Schaltvorgang obsolet
        lastSwitch = xTaskGetTickCount();
        queuePhaseCheck(phase, 1);
        if (debug) Serial.println("Schaltzustand der Phasen L" + String(phase) + ": eingeschaltet.");
      } else {
        if (phaseError[idx] != 0)
          if (debug)
            Serial.println("Phase " + String(phase) +
                           " weist einen Fehler auf -> aktuell keine Phasenschaltung möglich!");
        digitalWrite(PHASE_PIN[idx], HIGH);
        phaseOn[idx] = 0;
        checkError = 0;  // mögliche Integritätsfehler werden durch Schaltvorgang obsolet
        lastSwitch = xTaskGetTickCount();
        queuePhaseCheck(phase, 0);
        if (debug) Serial.println("Schaltzustand der Phasen L" + String(phase) + ": ausgeschaltet.");
      }
    }
    if (debug) Serial.println("SwitchTime Phase: " + String(lastSwitch));
    rc = xSemaphoreGive(mutexAmp);
    assert(rc == pdPASS);
  } else {
    if (panicMode != 0)
      if (debug) Serial.println("Notaus aktiv -> aktuell keine Phasenschaltung möglich!");
    if (phaseError[0] != 0)
      if (debug) Serial.println("Phase 1 weist einen Fehler auf -> aktuell keine Phasenschaltung möglich!");
    if (phaseError[1] != 0)
      if (debug) Serial.println("Phase 2 weist einen Fehler auf -> aktuell keine Phasenschaltung möglich!");
    if (phaseError[2] != 0)
      if (debug) Serial.println("Phase 3 weist einen Fehler auf -> aktuell keine Phasenschaltung möglich!");
    if (thermalLimit != 0)
      if (debug)
        Serial.println(
            "thermales Limit am Top-Sensor erreicht -> aktuell keine "
            "Phasenschaltung möglich!");
    if (thermalError != 0)
      if (debug) Serial.println("thermale Notabschaltung -> aktuell keine Phasenschaltung möglich!");
    if (thermalMaxOverheat != 0)
      if (debug)
        Serial.println(
            "thermales Limit am Max-Sensor erreicht -> aktuell keine "
            "Phasenschaltung möglich!");
  }
}
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
void loop() {
  // loop wird als Task nicht gebraucht
  vTaskDelete(nullptr);
}

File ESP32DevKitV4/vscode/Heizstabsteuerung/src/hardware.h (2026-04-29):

// hardware.h
#pragma once

// ╔═══════════════════════════════════════════════════════════════════════════╗
// ║  KALIBRIERUNGSWERTE                                                       ║
// ║  Nach Sensorwechsel oder Neukalibrierung anpassen.                        ║
// ║  Dienen als Initialwerte – zur Laufzeit via MQTT überschreibbar.          ║
// ╚═══════════════════════════════════════════════════════════════════════════╝

// ─── DS18B20-Sensoradressen ───────────────────────────────────────────────────
// Adresse per Debug-Modus (debug=1) auf dem Serial Monitor ermitteln:
//   DS18B20[n]: <Temp> °C (<Adresse>) => Slot <x>
// tempMax: Sensor h=max. – Überhitzungsabschaltung - Sensor oben auf dem Tank
// tempTop1: Sensor h=Top #1 – Temperaturüberwachung - sinnvolle Höhe wählen, z.B. 2/3 der Tankhöhe
// tempTop2: Sensor h=Top #2 – Temperaturüberwachung - parallel zu Sensor h=Top #1 (redundante Überwachung)
#define DS18B20_ADDR_MAX "0x28, 0xff, 0x64, 0x1f, 0x41, 0xe9, 0xb9, 0x17"   // tempMax  – Sensor h=max.
#define DS18B20_ADDR_TOP1 "0x28, 0xcb, 0x1d, 0x43, 0xd4, 0xe8, 0x21, 0x78"  // tempTop1 – Sensor h=Top #1
#define DS18B20_ADDR_TOP2 "0x28, 0xf3, 0xf8, 0x43, 0xd4, 0xad, 0x40, 0x63"  // tempTop2 – Sensor h=Top #2

// ─── ADC-Kalibrierung: Peaklast-Korrektur ────────────────────────────────────
// Kalibrierung auf den verwendeten Sensor erforderlich – Ausgleich von Toleranzen.
// Formel: ADC_Lx_CORR_INIT = Asoll / Aist × 15 A
//   (Asoll / ADC_Lx_corr = Aist / 15 A  =>  ADC_Lx_corr = Asoll / Aist × 15 A)
#define ADC_L1_CORR_INIT 15.00f  // Korrektur L1-Sensor (Peaklast)
#define ADC_L2_CORR_INIT 14.66f  // Korrektur L2-Sensor (Peaklast)
#define ADC_L3_CORR_INIT 14.96f  // Korrektur L3-Sensor (Peaklast)

// ─── ADC-Kalibrierung: Nullpunktkorrektur ────────────────────────────────────
// Basiskorrektur bei 0 A: Irms_korr = Irms − zeroCorr  (@0 A gemessen)
// Korrigiert Unzulänglichkeiten der Widerstände
#define ADC_L1_ZERO_CORR_INIT 0.12f
#define ADC_L2_ZERO_CORR_INIT 0.10f
#define ADC_L3_ZERO_CORR_INIT 0.11f

// ╔════════════════════════════════════════════════════════════════════════════╗
// ║  Pinning und Hardwareconfig                                                ║
// ║  DO NOT MODIFY UNLESS YOU KNOW WHAT YOU ARE DOING - CHANGES NOT NESSESARY  ║
// ╚════════════════════════════════════════════════════════════════════════════╝

// ─── GPIO-Pinbelegung ─────────────────────────────────────────────────────────
#define LED_ERROR 23
#define LED_MSG 4
#define LED_OK 19
#define ONE_WIRE_BUS 25

// Sensorpin für das Auslesen der Äquivalenzspannung des Phasestromsensors (STC-013)
#define ADC_L1 34
#define ADC_L2 35
#define ADC_L3 36

// Steuerpin Phase 1–3 – bleiben für Notabschaltungen aktiv
#define PHASE1 16
#define PHASE2 17
#define PHASE3 18
#define FAN0 32  // Steuerpin für die Lüftung on/off

// Kommunikation mit dem LCD-Display via I2C – SDA und SCL Pins
#define SDA_PIN 21
#define SCL_PIN 22

// ─── LCD-Konfiguration ────────────────────────────────────────────────────────
// Verbindung zum Display via I2C (Standard-Adresse 0x27), Zeilen und Spalten
#define LCDADRESS 0x27
#define LCDCOLUMNS 16
#define LCDROWS 2

// ─── DS18B20-Sensor-Konfiguration ─────────────────────────────────────────────
// 9 bit: ±0,5 °C / 93,75 ms  | 10 bit: ±0,25 °C / 187,5 ms
// 11 bit: ±0,125 °C / 375 ms | 12 bit: ±0,0625 °C / 750 ms
#define DS18B20_RESOLUTION 10
#define DS18B20_DELAY 20  // Wartezeit nach getriggerter Messung [ms]

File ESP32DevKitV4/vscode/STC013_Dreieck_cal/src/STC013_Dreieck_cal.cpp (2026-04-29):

// STC013_Dreieck_cal.cpp — Kalibrierungssketch für SCT-013 Stromsensoren an einem ESP32 (Dreiecksschaltung)
//
// Zweck:
//   Dieser Sketch misst die Ausgangsströme der drei Phasen über SCT-013-Stromsensoren
//   in einer Dreiecksschaltung mit zwei Schaltstufen und vergleicht die Messwerte
//   mit bekannten Referenzwerten (Zangenampermeter).
//   Aus der Abweichung werden korrigierte Kalibrierwerte für ADC_LX_corr und
//   ADC_LX_zeroCorr berechnet und über die serielle Schnittstelle ausgegeben.
//
// Schaltstufen (Dreiecksschaltung):
//   Stufe 1: Phase 1 + Phase 2 aktiv  → Heizstab zwischen L1 und L2
//   Stufe 2: Phase 1 + Phase 2 + Phase 3 aktiv → alle drei Wicklungen aktiv
//
// Verwendung:
//   1. Referenzmessungen mit einem Zangenampermeter an allen drei Phasen durchführen.
//   2. Stufe-1-Strom (L1, L2) in Irms_L1_xA / Irms_L2_xA eintragen.
//      Stufe-2-Strom (L3) in Irms_L3_xA eintragen.
//   3. Sketch flashen und seriellen Monitor öffnen (115200 Baud).
//   4. Die ausgegebenen Korrekturwerte in ADC_LX_corr / ADC_LX_zeroCorr übernehmen.

#include <DallasTemperature.h>
#include <EmonLib.h>  // Auswertung der SCT013-Sensoren
#include <OneWire.h>

// --- DS18B20 Temperatursensor ---
#define ONE_WIRE_BUS 25
int DS18B20_Count = 0;
OneWire oneWire(ONE_WIRE_BUS);
DallasTemperature myDS18B20(&oneWire);
DeviceAddress myDS18B20Address;
String Adresse;

// --- ADC-Pins und EmonLib-Instanzen ---
#define ADC_L1 34
#define ADC_L2 35
#define ADC_L3 36
float volatile amp1 = 0.0;
float volatile amp2 = 0.0;
float volatile amp3 = 0.0;
#define ZEROHYST 0.8
EnergyMonitor emon1;
EnergyMonitor emon2;
EnergyMonitor emon3;

// --- Kalibrierungsfaktoren (Peaklast-Korrektur) ---
// ADC_LX_corr_neu = (Irms_Referenz / Irms_gemessen) * ADC_LX_corr_alt
float ADC_L1_corr = 15.00;
float ADC_L2_corr = 15.00;
float ADC_L3_corr = 15.00;

// --- Nullpunkt-Korrektur ---
float ADC_L1_zeroCorr = 0.23;
float ADC_L2_zeroCorr = 0.23;
float ADC_L3_zeroCorr = 0.23;
unsigned long t;

// --- Referenzwerte vom Zangenampermeter ---
// L1 und L2: gemessen in Stufe 1 (Phase 1 + Phase 2 ein)
// L3:        gemessen in Stufe 2 (Phase 1 + Phase 2 + Phase 3 ein)
float Irms_L1_xA = 9.50;
float Irms_L2_xA = 10.77;
float Irms_L3_xA = 11.05;

// --- Steuerpins für die Phasenschalter (Solid-State-Relais) ---
#define PHASE1 16
#define PHASE2 17
#define PHASE3 18

void setup() {
  Serial.begin(115200);
  while (!Serial);
  Serial.println("Start Setup");

  Serial.println("Auslesen der DS18B20-Sensoren...");
  myDS18B20.begin();
  Serial.print("Anzahl gefundener 1-Wire-Geraete:  ");
  Serial.println(myDS18B20.getDeviceCount());
  DS18B20_Count = myDS18B20.getDS18Count();
  Serial.print("Anzahl gefundener DS18B20-Geraete: ");
  Serial.println(DS18B20_Count);
  Serial.print("Globale Aufloesung (Bit):        ");
  Serial.println(myDS18B20.getResolution());
  Serial.println("");
  delay(1500);

  emon1.current(ADC_L1, ADC_L1_corr);
  emon2.current(ADC_L2, ADC_L2_corr);
  emon3.current(ADC_L3, ADC_L3_corr);

  Serial.println("Initialisierung der Phasenschalter.");
  pinMode(PHASE1, OUTPUT);
  pinMode(PHASE2, OUTPUT);
  pinMode(PHASE3, OUTPUT);
  digitalWrite(PHASE1, HIGH);
  digitalWrite(PHASE2, HIGH);
  digitalWrite(PHASE3, HIGH);
}

void loop() {
  float Irms0;
  float Irms1;
  float mittelwert = 0.0;
  int i = 0;
  int iTime = 500;

  // --- Temperatursensoren auslesen ---
  Serial.println("");
  Serial.println("----------------------------------");
  Serial.println("Auswertung der Temperatursensoren:");
  Serial.println("----------------------------------");
  Serial.println("");

  myDS18B20.requestTemperatures();
  for (int i = 0; i < DS18B20_Count; i++) {
    Serial.print("DS18B20[");
    Serial.print(i);
    Serial.print("]: ");
    Serial.print(myDS18B20.getTempCByIndex(i));
    Serial.print(" *C (");
    myDS18B20.getAddress(myDS18B20Address, i);
    Adresse = "";
    for (uint8_t j = 0; j < 8; j++) {
      Adresse += "0x";
      if (myDS18B20Address[j] < 0x10) Adresse += "0";
      Adresse += String(myDS18B20Address[j], HEX);
      if (j < 7) Adresse += ", ";
    }
    Serial.println(Adresse + ")");
  }
  delay(1500);

  // ============================================================
  // === Nullmessung alle Sensoren (alle Phasen aus) ===
  // ============================================================

  // --- Nullmessung L1 ---
  Serial.println("");
  Serial.println("-------------------------------------------");
  Serial.println("Nullmessung L1 (alle Phasen aus):");
  Serial.println("-------------------------------------------");
  Serial.println("");
  i = 0;
  mittelwert = 0.0;
  while (i != 10) {
    t = micros();
    Irms0 = emon1.calcIrms(1480) - ADC_L1_zeroCorr;
    Serial.print(i);
    Serial.print(") Strom L1 aus: ");
    Serial.print(Irms0);
    Serial.print(" A; Zero-Korrektur: ");
    Serial.print(ADC_L1_zeroCorr);
    Serial.print(" [A]; Zeitstempel: ");
    Serial.print(micros() - t);
    Serial.print(" [µs] => ");
    Serial.print((micros() - t) / 20000.0);
    Serial.println(" Zyklen @50Hz");
    delay(iTime);
    if (i > 2) mittelwert += Irms0;
    i++;
  }
  mittelwert = mittelwert / 7.0;
  Serial.println("-----------------------------------------------------------");
  Serial.print("Anzustrebende Korrektur fuer ADC_L1_zeroCorr: ");
  Serial.print(ADC_L1_zeroCorr + mittelwert);
  Serial.println(" A");
  Serial.println("-----------------------------------------------------------");

  // --- Nullmessung L2 ---
  Serial.println("");
  Serial.println("-------------------------------------------");
  Serial.println("Nullmessung L2 (alle Phasen aus):");
  Serial.println("-------------------------------------------");
  Serial.println("");
  i = 0;
  mittelwert = 0.0;
  while (i != 10) {
    t = micros();
    Irms0 = emon2.calcIrms(1480) - ADC_L2_zeroCorr;
    Serial.print(i);
    Serial.print(") Strom L2 aus: ");
    Serial.print(Irms0);
    Serial.print(" A; Zero-Korrektur: ");
    Serial.print(ADC_L2_zeroCorr);
    Serial.print(" [A]; Zeitstempel: ");
    Serial.print(micros() - t);
    Serial.print(" [µs] => ");
    Serial.print((micros() - t) / 20000.0);
    Serial.println(" Zyklen @50Hz");
    delay(iTime);
    if (i > 2) mittelwert += Irms0;
    i++;
  }
  mittelwert = mittelwert / 7.0;
  Serial.println("-----------------------------------------------------------");
  Serial.print("Anzustrebende Korrektur fuer ADC_L2_zeroCorr: ");
  Serial.print(ADC_L2_zeroCorr + mittelwert);
  Serial.println(" A");
  Serial.println("-----------------------------------------------------------");
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

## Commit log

2023-11-05 ESP32-Programm V1.996 hinzugefügt
2023-11-05 Platine und Fritzing V1.996 ergänzt
    [Heizstabsteuerung.brd, Heizstabsteuerung.fzz, Heizstabsteuerung.sch]
2023-11-05 Update README.md
    Sensoren und Kalibrierung ergänzt
2023-11-11 Update V2.02 übertragen
    [Heizstabsteuerung.brd, Heizstabsteuerung.fzz, Heizstabsteuerung.sch]
2023-11-11 Update README.md
    Update auf PCB-Version V2.01
2023-11-11 Update README.md
    Display und Informatíonsinhalt erläutert
2024-05-20 SCCT013 Kalibrierungsunterstützung
    [Kalibrierung.xlsx]
2024-10-06 fix timing errors on DS18B20 & Integrety -> V2.1.6
    fixed possible timing errors while reading DS18B20 sensors
    fixed Integrety-errors when switching phases quickly
2024-10-06 fix display timing errors -> V2.1.7
    fixes display timing errors with reducing I2C speed from 400kH to 10kH
    (white screen or funny characters after operating over hours normaly)
2024-10-14 fix quick switches in integrety check -> V2.1.8
    fix quick switches in integrety check
2025-07-27 command IrmsOn und IrmsOff integrated
    IrmsOn -> calibration routine to get core Irms values without correction
    IrmsOff -> get core Irms values at 0A
2025-08-16 direct return response on command
    direct update of the switched phase after check of the switching result
2026-04-20 Delete ESP32DevKitV4/secrets.h
    outdated
2026-04-20 Delete ESP32DevKitV4/Heizstabsteuerung.ino
    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
2026-04-20 Delete ESP32DevKitV4/DS18B20_init/DS18B20_init.ino
    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
2026-04-20 Delete ESP32DevKitV4/SCT013_cal/Kalibrierung.xlsx
    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
    [Kalibrierung.xlsx]
2026-04-20 Delete ESP32DevKitV4/SCT013_cal/SCT013_cal_V2.ino.ino
    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
2026-04-29 Refactor DS18B20 sensor configuration and initialization
    Updated sensor address handling and configuration for DS18B20 temperature sensors. Removed unused definitions and improved initialization from hardware.h.
2026-04-29 Enhance SCT-013 calibration instructions in README
    Updated calibration instructions for SCT-013 current sensors, including separate projects for star and delta configurations. Added details on measurement procedures and parameters in the README.
